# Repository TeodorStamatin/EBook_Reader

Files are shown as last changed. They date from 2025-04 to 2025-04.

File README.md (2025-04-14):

# EBook_Reader

## Block Diagram
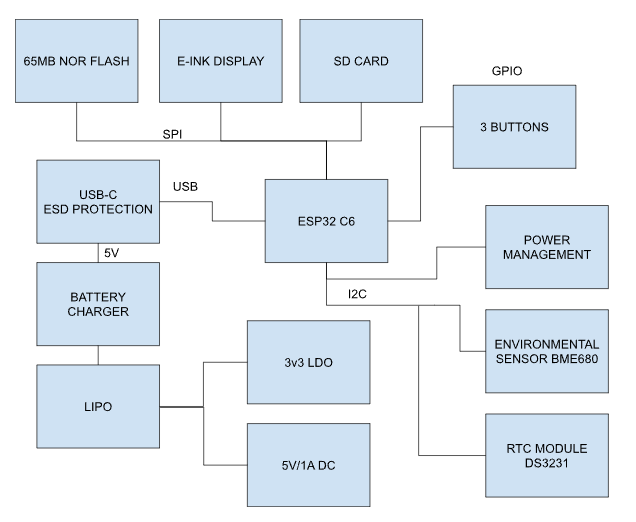
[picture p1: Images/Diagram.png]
Diagram


## BOM (Bill Of Materials)

| Component  | Supplier Link | Datasheet |
|---|---|---|
| 112A-TAAR-R03 | [Model](https://www.snapeda.com/parts/112A-TAAR-R03/Attend/view-part/) | [Datasheet](https://www.snapeda.com/parts/112A-TAAR-R03/Attend/datasheet/) |
| 744043680 | [Model](https://ro.mouser.com/ProductDetail/Wurth-Elektronik/744043680?qs=PGXP4M47uW6VkZq%252BkzjrHA%3D%3D) | [Datasheet](https://www.we-online.com/components/products/datasheet/744043680.pdf) |
| BD5229G-TR | [Model](https://www.digikey.ee/en/models/658502) | [Datasheet](https://www.rohm.com/datasheet?p=BD5229G&dist=Digi-key&media=referral&source=digi-key.com&campaign=Digi-key) |
| Capacitor 0402 | [Model](https://componentsearchengine.com/part-view/CC0402MRX5R5BB106/YAGEO) | [Datasheet](https://componentsearchengine.com/Datasheets/2/CC0402MRX5R5BB106.pdf) |
| CPH3225A | [Model](https://www.snapeda.com/parts/CPH3225A/Seiko+Instruments/view-part/?ref=eda) | [Datasheet](https://www.snapeda.com/parts/CPH3225A/Seiko%20Instruments/datasheet/) |
| Custom Button | [Model](https://industry.panasonic.com/global/en/products/control/switch/light-touch/number/evqpuj02k) | [Datasheet](https://industry.panasonic.com/global/en/downloads?tab=catalog&small_g_cd=203&part_no=EVQPUJ02K) |
| DS3231SN | [Model](https://www.snapeda.com/parts/DS3231SN%23/Analog+Devices/view-part/?ref=eda) | [Datasheet](https://www.snapeda.com/parts/DS3231SN%23/Analog%20Devices/datasheet/) |
| ESP32 WROVER 0805 Capacitor | [Model](https://ro.mouser.com/ProductDetail/KYOCERA-AVX/SD0805S020S1R0?qs=jCA%252BPfw4LHbpkAoSnwrdjw%3D%3D) | [Datasheet](https://ro.mouser.com/datasheet/2/40/schottky-3165252.pdf) |
| ESP32 WROVER BME680 Sensor | [Model](https://www.digikey.ro/en/models/7401317) | [Datasheet](https://www.bosch-sensortec.com/media/boschsensortec/downloads/datasheets/bst-bme680-ds001.pdf) |
| ESP32 WROVER MCP73831 Power Management | [Model](https://www.snapeda.com/parts/MCP73831T-2ACI/OT/Microchip/view-part/) | [Datasheet](https://www.snapeda.com/parts/MCP73831T-2ACI/OT/Microchip/datasheet/) |
| ESP32C6 Varistor 1812 | [Model](https://www.snapeda.com/parts/RC0603JR-070RL/Yageo/view-part/) | [Datasheet](https://www.snapeda.com/parts/RC0603JR-070RL/Yageo/datasheet/) |
| ESP32C6 WROOM-1-N8 | [Model](https://www.snapeda.com/parts/ESP32-C6-WROOM-1-N8/Espressif+Systems/view-part/?ref=eda) | [Datasheet](https://www.snapeda.com/parts/ESP32-C6-WROOM-1-N8/Espressif%20Systems/datasheet/) |
| FH34SRJ-24S-0.5SH | [Model](https://www.snapeda.com/parts/FH34SRJ-24S-0.5SH(99)/Hirose/view-part/) | [Datasheet](https://www.snapeda.com/parts/FH34SRJ-24S-0.5SH(99)/Hirose%20Connector/datasheet/) |
| LED Chip 0603 | [Model](https://grabcad.com/library/0603-smd-led-1) | [Datasheet](https://www.snapeda.com/parts/KP-1608SURCK/Kingbright/datasheet/) |
| MAX17048G+T10 | [Model](https://www.snapeda.com/parts/MAX17048G+T10/Analog+Devices/view-part/?ref=eda) | [Datasheet](https://www.snapeda.com/parts/MAX17048G+T10/Analog%20Devices/datasheet/) |
| MBR0530 Schottky Diode | [Model](https://www.snapeda.com/parts/MBR0530/Onsemi/view-part/?ref=eda) | [Datasheet](https://www.snapeda.com/parts/MBR0530/ON%20Semiconductor/datasheet/) |
| PGB1010603MR | [Model](https://www.snapeda.com/parts/PGB1010603MR/Littelfuse/view-part/?ref=eda) | [Datasheet](https://www.snapeda.com/parts/PGB1010603MR/Littelfuse%20Inc./datasheet/) |
| QWIIC Connector | [Model](https://www.snapeda.com/parts/PRT-14417/SparkFun/view-part/) | [Datasheet](https://www.snapeda.com/parts/PRT-14417/SparkFun%20Electronics/datasheet/) |
| RCL CPOL 3528 | [Model](https://www.snapeda.com/parts/TAJB475K025RNJ/AVX/view-part/?ref=dk&t=capacitor%203528&con_ref=None) | [Datasheet](https://s3.amazonaws.com/snapeda/datasheet/TAJB475K025RNJ_AVX.pdf) |
| Resistor 0402 | [Model](https://componentsearchengine.com/part-view/R0402%201%25%20100%20K%20(RC0402FR-07100KL)/YAGEO) | [Datasheet](https://www.yageo.com/upload/media/product/products/datasheet/rchip/PYu-RC_Group_51_RoHS_L_12.pdf) |
| SI1308EDL-T1-GE3 MOSFET | [Model](https://www.snapeda.com/parts/SI1308EDL-T1-GE3/Vishay+Siliconix/view-part/?ref=eda) | [Datasheet](https://www.snapeda.com/parts/SI1308EDL-T1-GE3/Vishay%20Siliconix/datasheet/) |
| SJ | [Model](https://grabcad.com/library/solder-jumpers-1) | [Datasheet]() |
| TPTP20R | [Model](https://ro.mouser.com/ProductDetail/Adafruit/3825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) | [Datasheet](https://cdn-shop.adafruit.com/product-files/3825/3825_diagram.PDF) |
| USB4110-GF-A | [Model](https://componentsearchengine.com/part-view/USB4110-GF-A/GCT%20(GLOBAL%20CONNECTOR%20TECHNOLOGY)) | [Datasheet](https://gct.co/files/drawings/usb4110.pdf) |
| USBLC6-2SC6Y | [Model](https://www.snapeda.com/parts/USBLC6-2SC6Y/STMicroelectronics/view-part/?ref=eda) | [Datasheet](https://www.snapeda.com/parts/USBLC6-2SC6Y/STMicroelectronics/datasheet/) |
| W25Q512JVEIQ | [Model](https://www.digikey.ro/en/models/10244706) | [Datasheet](https://www.winbond.com/resource-files/W25Q512JV%20SPI%20RevB%2006252019%20KMS.pdf) |
| XC6220A331MR-G | [Model](https://componentsearchengine.com/part-view/XC6220A331MR-G/Torex) | [Datasheet](https://product.torexsemi.com/system/files/series/xc6220.pdf) |

## Hardware Description
1. Microcontroller - ESP32-C6-WROOM-1-N8
The ESP32-C6 is the core processing unit responsible for handling all system operations, communication with sensors and modules, and power management.
- Architecture: RISC-V 32-bit
- Clock Speed: 160 MHz
- Wireless Connectivity: 2.4 GHz Wi-Fi 6, Bluetooth 5.0

2. Power Management & Battery
Battery Type: Li-Po (Lithium Polymer)
- Capacity: 3.7V, 1800mAh
- Charging Circuit: MCP73831T
- Input Voltage: 5V via USB-C
- Protection Features: Overcharge and deep discharge protection
- Voltage Regulator: LDO regulator ensures a stable 3.3V power supply to all components.

3. Display - E-Paper (E-Ink) Screen
- Size: 7.5 inches
- Resolution: 800x480 pixels
- Communication Interface: SPI

4. SD Card Module
- Type: MicroSD (Supports FAT32)
- Interface: SPI

5. External NOR Flash
- Capacity: 64MB
- Interface: SPI

6. Environmental Sensor - BME688
- Functions: Measures temperature, humidity, air pressure, and gas levels.
- Communication Interface: I2C

7. Real-Time Clock (RTC) - DS3231SN
- Functionality: Maintains time and date even when the system is powered off.
- Communication Interface: I2C

8. USB-C Connector & ESD Protection
- Functionality: Provides power input and data transfer capability.
- Protection: Integrated ESD protection and Schottky diode for reverse polarity safety.

9. Buttons & User Input
- Tactile Push Buttons

10. Communication Interfaces
- GPIO: Used for button controls and general I/O operations.
- SPI: Used for SD card, external flash memory, and e-paper display.
- I2C: Used for the BME688 environmental sensor and DS3231SN RTC module.
- UART: Used for debugging and serial communication.
- Wi-Fi & Bluetooth: Provided by ESP32-C6, allowing wireless connectivity.

## Power Consumption Estimation
| Component | Current Draw (mA) | Voltage (V) | Power (mW) |
|---|---|---|---|
| **ESP32-C6 (Wi-Fi active)** | 200 | 3.3 | 660 |
| **E-Paper Display (Updating)** | 40 | 3.3 | 132 |
| **BME688 Sensor (Measuring)**  | 3.1 | 3.3 | 10.23 |
| **RTC Module (Active)** | 0.15 | 3.3 | 0.495 |
| **SD Card (Active)** | 50 | 3.3 | 165 |
| **External NOR Flash** | 25 | 3.3 | 82.5 |
| **Total Estimated Power Consumption** | **~318.5mA** | 3.3V | **1050.72 mW** |

## ESP32-C6 Pin Mapping  

| Component | ESP32-C6 Pin(s) | Interface | Purpose |
|---|---|---|---|
| **E-Paper Display** | IO7 (MOSI), IO6 (SCK), IO10 (CS), IO5 (DC), IO23 (RST), IO3 (BUSY) | SPI | Transfers image data to the display and controls its state. |
| **MicroSD Card** | IO7 (MOSI), IO6 (SCK), IO4 (SS_SD), IO2 (MISO) | SPI | Allows storage and retrieval of e-book files. |
| **Environmental Sensor (BME688)** | IO21 (SDA), IO22 (SCL) | I2C | Reads temperature, humidity, pressure, and air quality data. |
| **RTC Module (DS3231)**  | IO21 (SDA), IO22 (SCL), IO18 (RST), IO1 (32KHz), IO0 (INT_RTC) | I2C | Keeps track of time even when ESP32 is off. |
| **External NOR Flash** | IO11 (CS), IO6 (SCK), IO2 (MISO), IO7 (MOSI) | SPI | Provides additional storage for application data. |
| **Battery Monitoring** | IO21 (SDA), IO22 (SCL) | I2C | Reads battery voltage and charge status. |
| **USB-C Connection** | GPIOs through voltage regulation | USB | Powers and programs the ESP32-C6. |
| **Control Buttons** | IO9 (BOOT), IO15 (CHANGE), EN (RESET) | GPIO | User input for device interactions. |

## Additional Design Notes  

- **Footprint Adjustments**:  
  - The **744043680 inductor** and **USB-C connector** footprints were modified to prevent design rule check (DRC) errors.  

- **Power Routing Constraints**:  
  - Not all power traces could be routed on the **top layer**, requiring some to be placed on the **bottom layer**.  
  - A **ground plane** is present on both the **top** and **bottom layers** for improved signal integrity and noise reduction.  

- **Component Placement**:  
  - The **component layout** closely follows the reference document to ensure optimal spacing and routing efficiency.  
  - The **battery fits perfectly** next to the PCB inside the enclosure.  

- **Button Alignment Issues**:  
  - The buttons **do not align perfectly** with their footprints, but they (hopefully) remain functional.  

- **Via Count and Stitching**:  
  - The design includes **79 vias**, which is a reasonable number for a project of this complexity.  
  - **Via stitching** was applied near the **ESP32-C6** to:  
    - Improve **ground return paths**.  
    - Manage **ground loops**.  
    - Enhance **heat dissipation**.  
    - Reduce **electromagnetic interference (EMI)**.

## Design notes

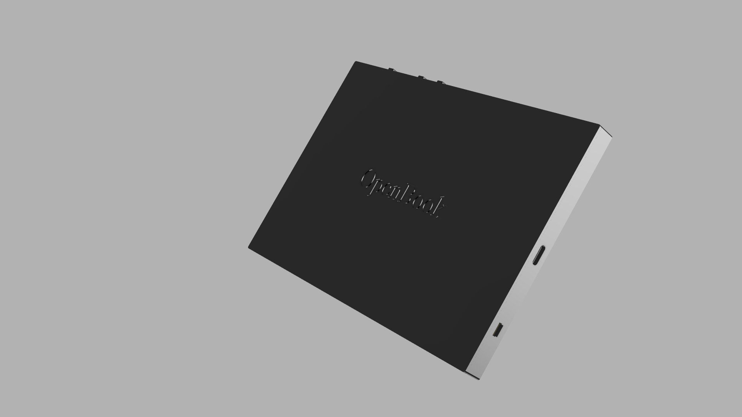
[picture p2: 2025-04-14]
Images/OpenBookReader2.png

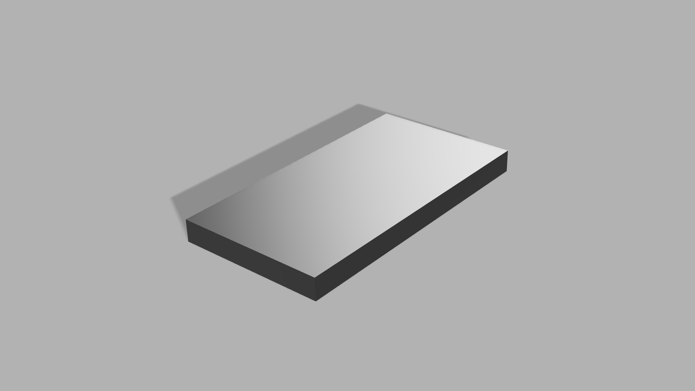
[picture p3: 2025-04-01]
Images/Battery.png

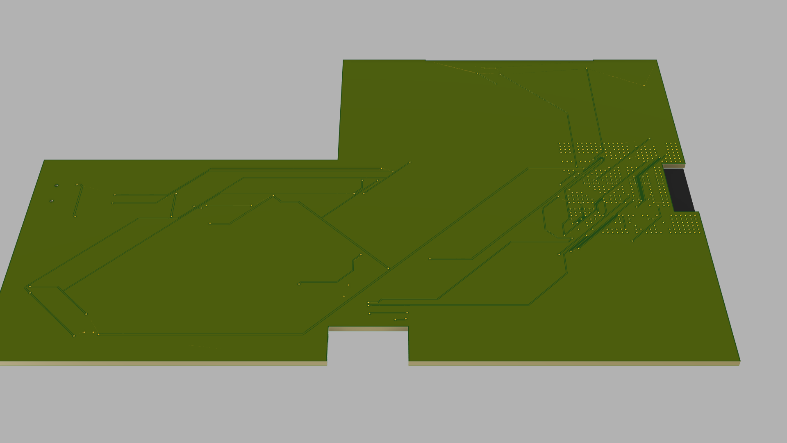
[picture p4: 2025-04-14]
Images/PCB_bottom.png

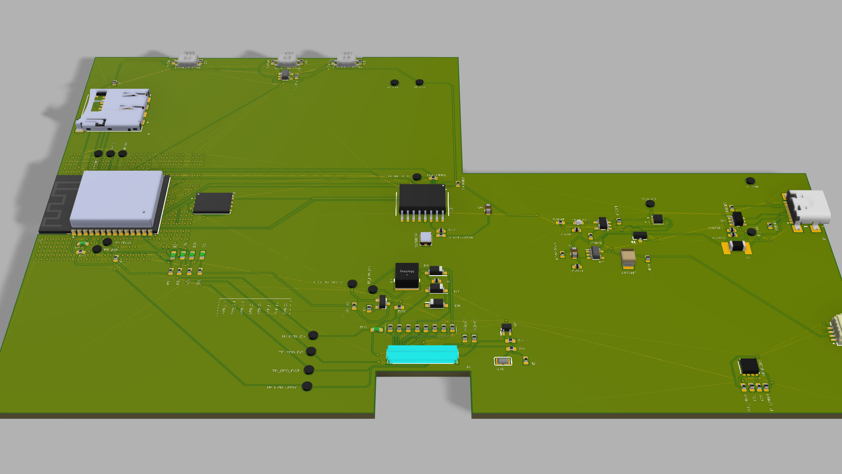
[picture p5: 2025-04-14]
Images/PCB_TOP.png

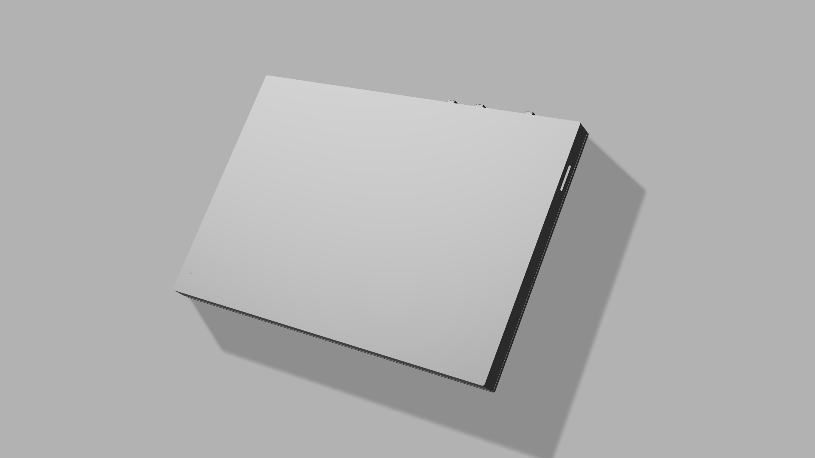
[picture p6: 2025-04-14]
Images/OpenBookReader1.png

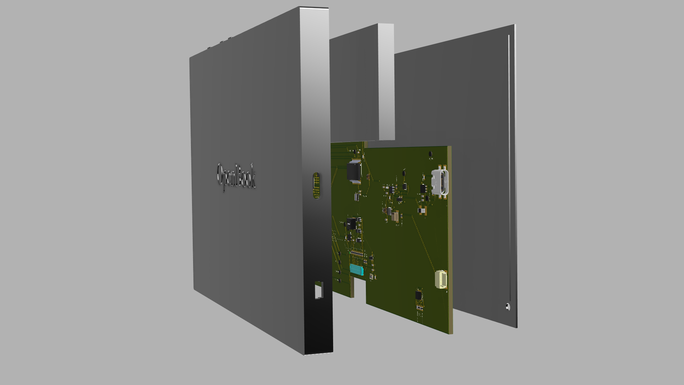
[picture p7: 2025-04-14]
Images/OpenBookReader_exploded1.png

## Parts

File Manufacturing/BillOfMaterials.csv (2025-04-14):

Qty,Value,Device,Package,Parts,Description,ARROW_PART_NUMBER,ARROW_PRICE-STOCK,AVAILABILITY,CENTROID_NOT_SPECIFIED,CHECK_PRICES,COPYRIGHT,DATASHEET,DESCRIPTION.1,DIGIKEY_DESCRIPTION,DIGIKEY_PART_NUMBER,HEIGHT,LEAD_FREE,MANUFACTURER_NAME,MANUFACTURER_PART_NUMBER,MF,MFR_NAME,MOUSER_PART_NUMBER,MOUSER_PRICE-STOCK,MOUSER_TESTING_PART_NUMBER,MOUSER_TESTING_PRICE-STOCK,MP,MPN,PACKAGE.1,POPULARITY,PREFIX,PRICE,PROD_ID,PURCHASE-URL,ROHS,SNAPEDA_LINK,SPICEMODEL,SPICEPREFIX,TEMPERATURE_RANGE_HIGH,TEMPERATURE_RANGE_LOW,TP_SIGNAL_NAME,VALUE.1,LCSC Part Number
1,,ADAFRUIT_LEDCHIP-LED0603,ADAFRUIT_CHIP-LED0603,CHG_LED,LED,,,,,,,,,,,,,,,,,,,,,,,,,,,,,,,,,,,,
1,,SJ,SJ,SJ1,SMD solder JUMPER,,,,,,,,,,,,,,,,,,,,,,,,3,,,,,,,,,,,,
1,0.1uF/50V,EAGLE-LTSPICE_CC0402,ESP32_WROVER_EAGLE-LTSPICE_C0402,EPD_C3,CAPACITOR, European symbol,,,,,,,,,,,,,,,,,,,,,,,,,,,,,,,NONE,C,,,,,
1,0.47,ESP32_WROVER_EAGLE-LTSPICE_RR0402,ESP32_WROVER_EAGLE-LTSPICE_R0402,R7,RESISTOR, European symbol,,,,,,,,,,,,,,,,,,,,,,,,,,,,,,,NONE,R,,,,,
1,100K,ESP32_WROVER_EAGLE-LTSPICE_RR0402,ESP32_WROVER_EAGLE-LTSPICE_R0402,R4PWRUSB1,RESISTOR, European symbol,,,,,,,,,,,,,,,,,,,,,,,,,,,,,,,NONE,R,,,,,
9,100nF,EAGLE-LTSPICE_CC0402,ESP32_WROVER_EAGLE-LTSPICE_C0402,C1USB, C2USB1, C6, C21, C22, C24, C25, C26, C_DELAY,CAPACITOR, European symbol,,,,,,,,,,,,,,,,,,,,,,,,,,,,,,,NONE,C,,,,,
1,100uF,RCL_CPOL-EUCT3528,RCL_CT3528,C5TANT,POLARIZED CAPACITOR, European symbol,,,,,,,,,,,,,,,,,,,,,,,,0,,,,,,,,C,,,,,
16,10K,ESP32_WROVER_EAGLE-LTSPICE_RR0402,ESP32_WROVER_EAGLE-LTSPICE_R0402,R6, R10, R11_CL1, R12_PINH, R13_PINH, R14_PINH1, R15_PINH1, R16, R17, R18, R19, R20, R21, R_BOOT, R_CHANGE, R_RESET,RESISTOR, European symbol,,,,,,,,,,,,,,,,,,,,,,,,,,,,,,,NONE,R,,,,,
1,10uF,EAGLE-LTSPICE_CC0402,ESP32_WROVER_EAGLE-LTSPICE_C0402,C7,CAPACITOR, European symbol,,,,,,,,,,,,,,,,,,,,,,,,,,,,,,,NONE,C,,,,,
1,112A-TAAR-R03_ATTEND,112A-TAAR-R03_ATTEND,112ATAARR03ATTEND,J2,Micro SD Card Socket, Push-Push Type, Top Mount, SMT, H=1.83mm, 10u,,,,,,,,Micro SD Card Socket, Push-Push Type, Top Mount, SMT, H=1.83mm, 10u,,,1.9mm,,ATTEND,112A-TAAR-R03 ATTEND,,,,,,,,,,,,,,,,,,
1,15,ESP32_WROVER_EAGLE-LTSPICE_RR0402,ESP32_WROVER_EAGLE-LTSPICE_R0402,R_CAPACITOR,RESISTOR, European symbol,,,,,,,,,,,,,,,,,,,,,,,,,,,,,,,NONE,R,,,,,
1,1uF,EAGLE-LTSPICE_CC0402,ESP32_WROVER_EAGLE-LTSPICE_C0402,C23,CAPACITOR, European symbol,,,,,,,,,,,,,,,,,,,,,,,,,,,,,,,NONE,C,,,,,
9,1uF/50V,EAGLE-LTSPICE_CC0402,ESP32_WROVER_EAGLE-LTSPICE_C0402,EPD_C1, EPD_C2, EPD_C6, EPD_C7, EPD_C8, EPD_C9, EPD_C10, EPD_C11, EPD_C12,CAPACITOR, European symbol,,,,,,,,,,,,,,,,,,,,,,,,,,,,,,,NONE,C,,,,,
1,02.feb,ESP32_WROVER_EAGLE-LTSPICE_RR0402,ESP32_WROVER_EAGLE-LTSPICE_R0402,R5,RESISTOR, European symbol,,,,,,,,,,,,,,,,,,,,,,,,,,,,,,,NONE,R,,,,,
1,200,ESP32_WROVER_EAGLE-LTSPICE_RR0402,ESP32_WROVER_EAGLE-LTSPICE_R0402,R8BAT,RESISTOR, European symbol,,,,,,,,,,,,,,,,,,,,,,,,,,,,,,,NONE,R,,,,,
2,20V/4.2A/52mO/1.4W,ESP32_WROVER_SPARKFUN-DISCRETESEMI_MOSFET_PCH-DMG2305UX-7,ESP32_WROVER_SPARKFUN-DISCRETESEMI_SOT23-3,Q1, Q3,P-channel MOSFETs,,,,,,,,,,,,,,,,,,,,,,,,,,,TRAN-14388,,,,,,,,,20V/4.2A/52mO/1.4W,
1,2K,ESP32_WROVER_EAGLE-LTSPICE_RR0402,ESP32_WROVER_EAGLE-LTSPICE_R0402,R9BAT,RESISTOR, European symbol,,,,,,,,,,,,,,,,,,,,,,,,,,,,,,,NONE,R,,,,,
4,4.7uF,EAGLE-LTSPICE_CC0402,ESP32_WROVER_EAGLE-LTSPICE_C0402,C3BAT, C4BAT, C9BAT, C10BAT,CAPACITOR, European symbol,,,,,,,,,,,,,,,,,,,,,,,,,,,,,,,NONE,C,,,,,
1,4.7uF/25V,EAGLE-LTSPICE_CC0402,ESP32_WROVER_EAGLE-LTSPICE_C0402,C8,CAPACITOR, European symbol,,,,,,,,,,,,,,,,,,,,,,,,,,,,,,,NONE,C,,,,,
2,5K1,ESP32_WROVER_EAGLE-LTSPICE_RR0402,ESP32_WROVER_EAGLE-LTSPICE_R0402,R2USB, R3USB1,RESISTOR, European symbol,,,,,,,,,,,,,,,,,,,,,,,,,,,,,,,NONE,R,,,,,
1,68uH,744043680IND_4828-WE-TPC_WRE,IND_4828-WE-TPC_WRE,L2,,,,,,,Copyright (C) 2024 Ultra Librarian. All rights reserved.,,,,,,,,744043680,,Wurth Electronics,,,,,,,,,,,,,,,,,,,,,
1,BD5229G-TR,BD5229G-TR,SOT95P280X125-5N,IC2,Voltage Detector with Adjustable Delay Time: CMOS processes are utilized to develop high precision, low current consumption CMOS reset ICs that allow arbitrary setting of the delay time. The extensive lineup includes both Nch Open Drain and CMOS output types in a wide range of detection voltages (from 2.3V to 6.0V, in 0.1V steps), enabling selection of the ideal solution based on customer requirements. In addition, the entire series is of course both lead-free and RoHS-compliant.,,,,,,,,Voltage Detector with Adjustable Delay Time: CMOS processes are utilized to develop high precision, low current consumption CMOS reset ICs that allow arbitrary setting of the delay time. The extensive lineup includes both Nch Open Drain and CMOS output types in a wide range of detection voltages (from 2.3V to 6.0V, in 0.1V steps), enabling selection of the ideal solution based on customer requirements. In addition, the entire series is of course both lead-free and RoHS-compliant.,,,1.25mm,,ROHM Semiconductor,BD5229G-TR,,,755-BD5229G-TR,https://www.mouser.co.uk/ProductDetail/ROHM-Semiconductor/BD5229G-TR?qs=4kLU8WoGk0vvnhrrYwdszw%3D%3D,,,,,,,,,,,,,,,
3,BUTTON_CUSYOMV1,BUTTON_CUSYOMV1,MYBUTTON,BOOT_BUTTON, CHANGE_BUTTON, RESET_BUTTON,,,,,,,,,,,,,,,,,,,,,,,,,,,,,,,,,,,,,,
1,CPH3225A,CPH3225A,CAPCP3225X100N,SUPERCAP,Cap 0.011F 3.3V 1210 Flat Check availability,,,Not in stock,,https://www.snapeda.com/parts/CPH3225A/Seiko+Instruments/view-part/?ref=eda,,, 11 mF (EDLC) Supercapacitor 3.3 V 1210 (3225 Metric) - - ,,,,,,,Seiko Instruments,,,,,,CPH3225A,,1210 Seiko,,,None,,https://www.snapeda.com/api/url_track_click_mouser/?unipart_id=562593&manufacturer=Seiko Instruments&part_name=CPH3225A&search_term=None,,https://www.snapeda.com/parts/CPH3225A/Seiko+Instruments/view-part/?ref=snap,,,,,,,
1,DS3231SN#,DS3231SN#,SOIC127P1032X265-16N,U5,Real Time Clock Serial 16-Pin SOIC W T/R     Check availability,,,In Stock,,https://www.snapeda.com/parts/DS3231SN%23/Analog+Devices/view-part/?ref=eda,,, Extremely Accurate I?C-Integrated RTC/TCXO/Crystal ,,,,,,,Analog Devices,,,,,,DS3231SN#,,SOIC-16 Maxim,,,None,,https://www.snapeda.com/api/url_track_click_mouser/?unipart_id=99048&manufacturer=Analog Devices&part_name=DS3231SN#&search_term=None,,https://www.snapeda.com/parts/DS3231SN%23/Analog+Devices/view-part/?ref=snap,,,,,,,
1,ESP32-C6-WROOM-1-N8,ESP32-C6-WROOM-1-N8,XCVR_ESP32-C6-WROOM-1-N8,U2,Check availability,,,In Stock,,https://www.snapeda.com/parts/ESP32-C6-WROOM-1-N8/Espressif+Systems/view-part/?ref=eda,,, Multiprotocol Modules ESP32-C6 module, Wi-Fi 6 in 2.4 GHz band, Bluetooth 5, Zigbee 3.0 and Thread. ESP34-WROOM Compatible - ENGINEERING SAMPLE ,,,,,,,Espressif Systems,,,,,,ESP32-C6-WROOM-1-N8,,None,,,None,,,,https://www.snapeda.com/parts/ESP32-C6-WROOM-1-N8/Espressif+Systems/view-part/?ref=snap,,,,
1,ESP32C6_VARISTORCN1812,ESP32C6_VARISTORCN1812,ESP32C6_VARISTOR_CT/CN1812,R1,VARISTOR,,,,,,,,,,,,,,,,,,,,,,,,0,,,,,,,,,,,,,
2,ESP32_WROVER_AVX---SD0805S020S1R0_AVX_SD0805S020S1R0_0_0AVX_SD0805S020S1R0_0_0,ESP32_WROVER_AVX---SD0805S020S1R0_AVX_SD0805S020S1R0_0_0AVX_SD0805S020S1R0_0_0,ESP32_WROVER_AVX---SD0805S020S1R0_AVX_SD0805S020S1R0_0,D2, D6,Schottky Barrier Rectifier Diode,,,,No,,,http://datasheets.avx.com/schottky.pdf,,DIODE SCHOTTKY 20V 1A 0805,478-7800-1-ND,,yes,,,AVX,,581-SD0805S020S1R0,,,,,,0805 (2012 metric),,D,,,,yes,,,,+125°C,-55°C,,,
1,ESP32_WROVER_BME680_BME680,ESP32_WROVER_BME680_BME680,ESP32_WROVER_BME680_PSON80P300X300X100-8N,SENSOR2,Integrated Environmental Unit,,,Unavailable,,,,, Integrated Environmental Unit ,,,,,,,Bosch Sensortec,,,,,,BME680,,LGA-8 Bosch Tools,,,None,,,,,,,,,,,
1,ESP32_WROVER_SPARKFUN-IC-POWER_MCP73831,ESP32_WROVER_SPARKFUN-IC-POWER_MCP73831,ESP32_WROVER_SPARKFUN-IC-POWER_SOT23-5,U1,MCP73831T Li-Ion, Li-Pol Controller,,,,,,,,,,,,,,,,,,,,,,,,,,,IC-09995,,,,,,,,,,
1,FH34SRJ-24S-0.5SH_99_,FH34SRJ-24S-0.5SH_99_,FH34SRJ24S05SH99,J3, (0.50mm) Surface Mount, Right Angle,,,,,,,,24 Position FFC, FPC Connector Contacts, (0.50mm) Surface Mount, Right Angle,,,1.1mm,,Hirose,FH34SRJ-24S-0.5SH(99),,,798-FH34SRJ24S05SH99,https://www.mouser.co.uk/ProductDetail/Hirose-Connector/FH34SRJ-24S-0.5SH99
1,MAX17048G+T10,MAX17048G+T10,SON50P200X200X80-9N,U4,Check availability,,,In Stock,,https://www.snapeda.com/parts/MAX17048G+T10/Analog+Devices/view-part/?ref=eda,,, 3µA 1-Cell/2-Cell Fuel Gauge with ModelGauge ,,,,,,,Analog Devices,,,,,,MAX17048G+T10,,TDFN-8 Maxim,,,None,,https://www.snapeda.com/api/url_track_click_mouser/?unipart_id=329239&manufacturer=Analog Devices&part_name=MAX17048G+T10&search_term=None,,https://www.snapeda.com/parts/MAX17048G+T10/Analog+Devices/view-part/?ref=snap,,,,,,,
3,MBR0530,MBR0530,SOD3716X135N,D3, D4, D5,ON SEMICONDUCTOR - MBR0530 - DIODE, SCHOTTKY, 0.5A, 30V, SOD-123,,,In Stock,,https://www.snapeda.com/parts/MBR0530/Onsemi/view-part/?ref=eda,,, Diode Schottky 30 V 500mA Surface Mount SOD-123 ,,,,,,,ON Semiconductor,,,,,,MBR0530,,SOD-123-2 ON Semiconductor,,,None,,https://www.snapeda.com/api/url_track_click_mouser/?unipart_id=179458&manufacturer=ON Semiconductor&part_name=MBR0530&search_term=None,,https://www.snapeda.com/parts/MBR0530/Onsemi/view-part/?ref=snap,,,,,,,
6,PGB1010603MR,PGB1010603MR,DIOC1608X36N,D7, D8, D9, D10, D11, D12,Check availability,,,In Stock,,https://www.snapeda.com/parts/PGB1010603MR/Littelfuse/view-part/?ref=eda,,, 150V (Typ) Clamp - Ipp Tvs Diode Surface Mount 0603 (1608 Metric) ,,,,,,,Littelfuse Inc.,,,,,,PGB1010603MR,,0603 Littelfuse Inc.,,,None,,https://www.snapeda.com/api/url_track_click_mouser/?unipart_id=5659453&manufacturer=Littelfuse Inc.&part_name=PGB1010603MR&search_term=None,,https://www.snapeda.com/parts/PGB1010603MR/Littelfuse/view-part/?ref=snap,,,,,,,
1,QWIIC_RIGHT_ANGLE,QWIIC_CONNECTORJS-1MM,JST04_1MM_RA,J4,SparkFun I2C Standard Qwiic Connector,,,,,,,,,,,,,,,,,,,,,,,,,,,CONN-13694,,,,,,,,,QWIIC_RIGHT_ANGLE,
1,SAMACSYS_PARTS_USB4110-GF-A,SAMACSYS_PARTS_USB4110-GF-A,SAMACSYS_PARTS_USB4110GFA,J1,CONN USB 2.0 TYPE-C R/A SMT,,,,,,,,CONN USB 2.0 TYPE-C R/A SMT,,,3.26mm,,GCT (GLOBAL CONNECTOR TECHNOLOGY),USB4110-GF-A,,,640-USB4110-GF-A,https://www.mouser.co.uk/ProductDetail/GCT/USB4110-GF-A
1,SI1308EDL-T1-GE3,SI1308EDL-T1-GE3,SOT65P210X110-3N,Q2,MOSFET N-Ch 30V 1.5A TrenchFET SC70 Vishay Si1308EDL-T1-GE3 N-channel MOSFET Transistor, 1.5 A, 30 V, 3-Pin SC-70,,,In Stock,,https://www.snapeda.com/parts/SI1308EDL-T1-GE3/Vishay+Siliconix/view-part/?ref=eda,,, Si1308EDL-T1-GE3 N-channel MOSFET Transistor, 1.5 A, 30 V, 3-Pin SC-70 | Siliconix / Vishay SI1308EDL-T1-GE3 ,,,,,,,Vishay Siliconix,,,,,,SI1308EDL-T1-GE3,,SOT-323 Vishay Semiconductor,,,None,,https://www.snapeda.com/api/url_track_click_mouser/?unipart_id=274603&manufacturer=Vishay Siliconix&part_name=SI1308EDL-T1-GE3&search_term=None,,https://www.snapeda.com/parts/SI1308EDL-T1-GE3/Vishay+Siliconix/view-part/?ref=snap,,,,
17,TPTP20R,TPTP20R,TP20R,TP_3V3, TP_EPD_3V3, TP_EPD_3V3_C, TP_EPD_BUSY, TP_EPD_CS, TP_EPD_DC, TP_EPD_RST, TP_GND, TP_GND1, TP_INT_RTC, TP_MISO, TP_MOSI, TP_RX, TP_SCK, TP_TX, TP_VBAT, TP_VBUS,Test pad,,,,,,,,,,,,,,,,,,,,,,,,2,,,,,,,,,,,,,
1,USBLC6-2SC6Y,USBLC6-2SC6Y,SOT95P280X145-6N,D1,Low Cap. ESD Protection Auto SOT-23-6 STMicroelectronics USBLC6-2SC6Y, Dual Uni-Directional TVS Diode Array, 6-Pin SOT-23,,,In Stock,,https://www.snapeda.com/parts/USBLC6-2SC6Y/STMicroelectronics/view-part/?ref=eda,,, 17V Clamp 5A (8/20µs) Ipp Tvs Diode Surface Mount SOT-23-6 ,,,,,,,STMicroelectronics,,,,,,USBLC6-2SC6Y,,SOT-23-6 STMicroelectronics,,,None,,,,https://www.snapeda.com/parts/USBLC6-2SC6Y/STMicroelectronics/view-part/?ref=snap,,,,,,,
1,W25Q512JVEIQ,W25Q512JVEIQ,SON127P600X800X80-9N,U6,Check availability,,,In Stock,,https://www.snapeda.com/parts/W25Q512JVEIQ/Winbond+Electronics/view-part/?ref=eda,,, FLASH - NOR Memory IC 512Mb (64M x 8) SPI - Quad I/O 133 MHz 8-WSON (8x6) ,,,,,,,Winbond Electronics,,,,,,W25Q512JVEIQ,,Package ,,,None,,,,https://www.snapeda.com/parts/W25Q512JVEIQ/Winbond+Electronics/view-part/?ref=snap,,,,,,,
1,XC6220A331MR-G,XC6220A331MR-G,SOT95P280X120-5N,IC1,LDO Voltage Regulators,,,,,,,,LDO Voltage Regulators,,,1.2mm,,Torex,XC6220A331MR-G,,,865-XC6220A331MR-G,https://www.mouser.co.uk/ProductDetail/Torex-Semiconductor/XC6220A331MR-G

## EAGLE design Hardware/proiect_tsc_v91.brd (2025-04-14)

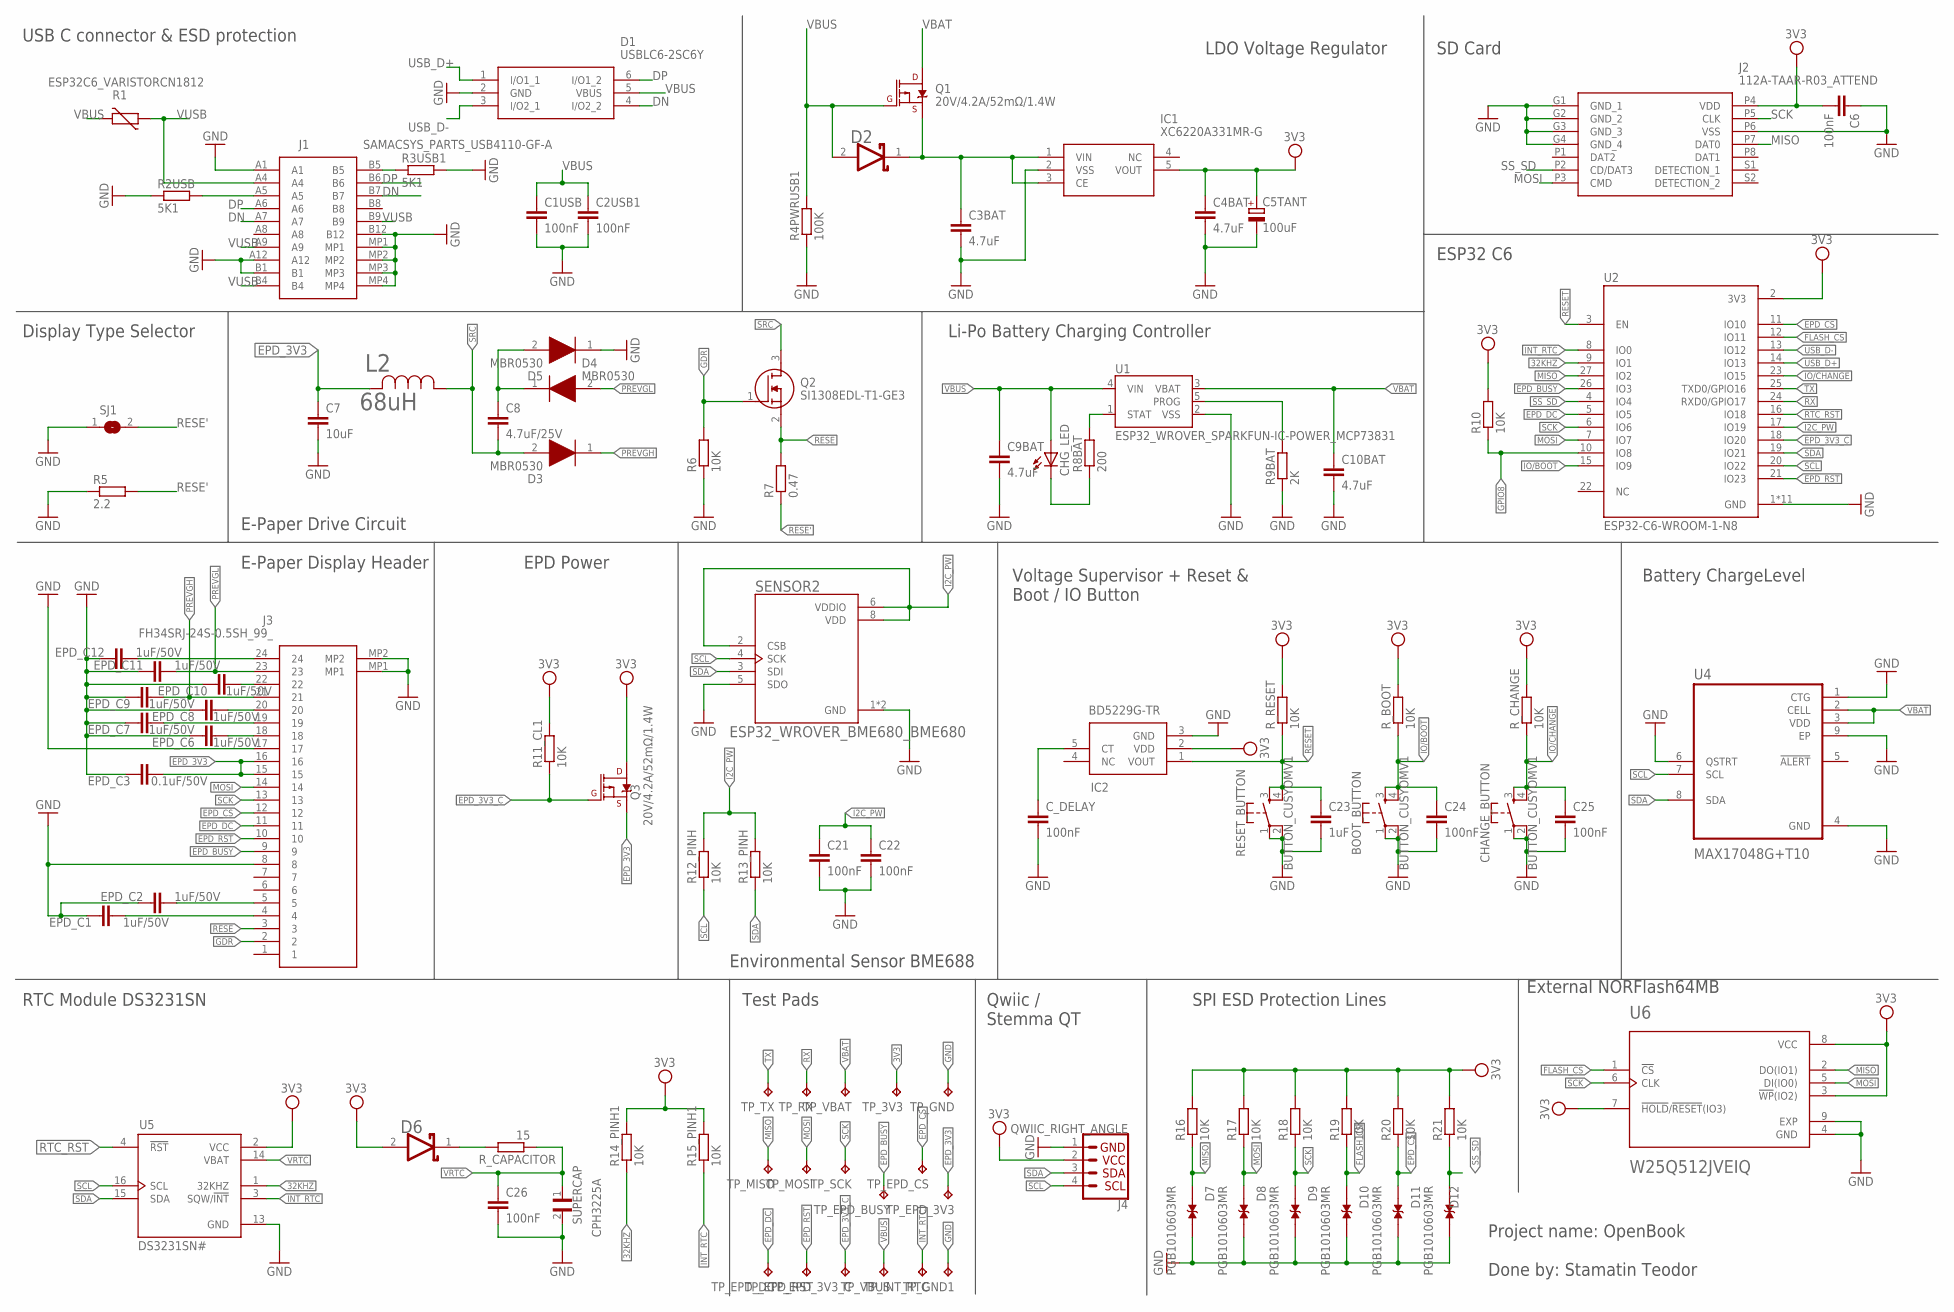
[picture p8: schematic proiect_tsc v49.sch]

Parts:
BOOT_BUTTON: BUTTON_CUSYOMV1; MYBUTTON
C1USB, C2USB1, C6, C21, C22, C24, C25, C26: 100nF; ESP32_WROVER_EAGLE-LTSPICE_C0402
C3BAT, C4BAT, C9BAT, C10BAT: 4.7uF; ESP32_WROVER_EAGLE-LTSPICE_C0402
C5TANT: 100uF; RCL_CT3528
C7: 10uF; ESP32_WROVER_EAGLE-LTSPICE_C0402
C8: 4.7uF/25V; ESP32_WROVER_EAGLE-LTSPICE_C0402
C23: 1uF; ESP32_WROVER_EAGLE-LTSPICE_C0402
CHANGE_BUTTON: BUTTON_CUSYOMV1; MYBUTTON
CHG_LED: ADAFRUIT_LEDCHIP-LED0603; ADAFRUIT_CHIP-LED0603
C_DELAY: 100nF; ESP32_WROVER_EAGLE-LTSPICE_C0402
D1: USBLC6-2SC6Y; SOT95P280X145-6N
D2, D6: ESP32_WROVER_AVX---SD0805S020S1R0_AVX_SD0805S020S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; ESP32_WROVER_AVX---SD0805S020S1R0_AVX_SD0805S020S1R0_0
D3, D4, D5: MBR0530; SOD3716X135N
D7, D8, D9, D10, D11, D12: PGB1010603MR; DIOC1608X36N
EPD_C1, EPD_C2, EPD_C6, EPD_C7, EPD_C8, EPD_C9, EPD_C10, EPD_C11, EPD_C12: 1uF/50V; ESP32_WROVER_EAGLE-LTSPICE_C0402
EPD_C3: 0.1uF/50V; ESP32_WROVER_EAGLE-LTSPICE_C0402
IC1: XC6220A331MR-G; SOT95P280X120-5N
IC2: BD5229G-TR; SOT95P280X125-5N
J1: SAMACSYS_PARTS_USB4110-GF-A; SAMACSYS_PARTS_USB4110GFA
J2: 112A-TAAR-R03_ATTEND; 112ATAARR03ATTEND
J3: FH34SRJ-24S-0.5SH_99_; FH34SRJ24S05SH99
J4: QWIIC_RIGHT_ANGLE; JST04_1MM_RA
L2: 68uH; IND_4828-WE-TPC_WRE
Q1, Q3: 20V/4.2A/52mΩ/1.4W; ESP32_WROVER_SPARKFUN-DISCRETESEMI_SOT23-3
Q2: SI1308EDL-T1-GE3; SOT65P210X110-3N
R1: ESP32C6_VARISTORCN1812; ESP32C6_VARISTOR_CT/CN1812
R2USB, R3USB1: 5K1; ESP32_WROVER_EAGLE-LTSPICE_R0402
R4PWRUSB1: 100K; ESP32_WROVER_EAGLE-LTSPICE_R0402
R5: 2.2; ESP32_WROVER_EAGLE-LTSPICE_R0402
R6, R10, R11_CL1, R12_PINH, R13_PINH, R14_PINH1, R15_PINH1, R16, R17, R18, R19, R20, R21: 10K; ESP32_WROVER_EAGLE-LTSPICE_R0402
R7: 0.47; ESP32_WROVER_EAGLE-LTSPICE_R0402
R8BAT: 200; ESP32_WROVER_EAGLE-LTSPICE_R0402
R9BAT: 2K; ESP32_WROVER_EAGLE-LTSPICE_R0402
RESET_BUTTON: BUTTON_CUSYOMV1; MYBUTTON
R_BOOT: 10K; ESP32_WROVER_EAGLE-LTSPICE_R0402
R_CAPACITOR: 15; ESP32_WROVER_EAGLE-LTSPICE_R0402
R_CHANGE: 10K; ESP32_WROVER_EAGLE-LTSPICE_R0402
R_RESET: 10K; ESP32_WROVER_EAGLE-LTSPICE_R0402
SENSOR2: ESP32_WROVER_BME680_BME680; ESP32_WROVER_BME680_PSON80P300X300X100-8N
SJ1: SJ
SUPERCAP: CPH3225A; CAPCP3225X100N
TP_3V3: TPTP20R; TP20R
TP_EPD_3V3, TP_EPD_3V3_C: TPTP20R; TP20R
TP_EPD_BUSY: TPTP20R; TP20R
TP_EPD_CS: TPTP20R; TP20R
TP_EPD_DC: TPTP20R; TP20R
TP_EPD_RST: TPTP20R; TP20R
TP_GND, TP_GND1: TPTP20R; TP20R
TP_INT_RTC: TPTP20R; TP20R
TP_MISO: TPTP20R; TP20R
TP_MOSI: TPTP20R; TP20R
TP_RX: TPTP20R; TP20R
TP_SCK: TPTP20R; TP20R
TP_TX: TPTP20R; TP20R
TP_VBAT: TPTP20R; TP20R
TP_VBUS: TPTP20R; TP20R
U1: ESP32_WROVER_SPARKFUN-IC-POWER_MCP73831; ESP32_WROVER_SPARKFUN-IC-POWER_SOT23-5
U2: ESP32-C6-WROOM-1-N8; XCVR_ESP32-C6-WROOM-1-N8
U4: MAX17048G+T10; SON50P200X200X80-9N
U5: DS3231SN#; SOIC127P1032X265-16N
U6: W25Q512JVEIQ; SON127P600X800X80-9N

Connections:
3V3: C4BAT.1, C5TANT.+, C6.2, D6.2 (ANODE), IC1.5 (VOUT), IC2.2 (VDD), J2.P4 (VDD), J4.2, Q3.3 (D), R10.2, R11_CL1.2, R14_PINH1.2, R15_PINH1.2, R16.2, R17.2, R18.2, R19.2, R20.2, R21.2, R_BOOT.2, R_CHANGE.2, R_RESET.2, TP_3V3.TP, U2.2 (3V3), U5.2 (VCC), U6.3 (!WP!(IO2)), U6.7 (!HOLD!/!RESET!(IO3)), U6.8 (VCC)
32KHZ: R14_PINH1.1, U2.9 (IO1), U5.1 (32KHZ)
DN: D1.4 (I/O2_2), J1.A7, J1.B7
DP: D1.6 (I/O1_2), J1.A6, J1.B6
EPD_3V3: C7.1, EPD_C3.2, J3.15, J3.16, L2.2, Q3.2 (S), TP_EPD_3V3.TP
EPD_3V3_C: Q3.1 (G), R11_CL1.1, TP_EPD_3V3_C.TP, U2.18 (IO20)
EPD_BUSY: J3.9, TP_EPD_BUSY.TP, U2.26 (IO3)
EPD_CS: D11.1, J3.12, R20.1, TP_EPD_CS.TP, U2.11 (IO10)
EPD_DC: J3.11, TP_EPD_DC.TP, U2.5 (IO5)
EPD_RST: J3.10, TP_EPD_RST.TP, U2.21 (IO23)
FLASH_CS: D10.1, R19.1, U2.12 (IO11), U6.1 (!CS)
GDR: J3.2, Q2.1 (G), R6.2
GND: BOOT_BUTTON.1, BOOT_BUTTON.2, C1USB.2, C2USB1.2, C3BAT.2, C4BAT.2, C5TANT.-, C6.1, C7.2, C9BAT.2, C10BAT.2, C21.2, C22.2, C23.2, C24.2, C25.2, C26.2, CHANGE_BUTTON.1, CHANGE_BUTTON.2, C_DELAY.2, D1.2 (GND), D5.1 (K), D7.2, D8.2, D9.2, D10.2, D11.2, D12.2, EPD_C1.1, EPD_C2.1, EPD_C3.1, EPD_C6.1, EPD_C7.1, EPD_C8.1, EPD_C9.1, EPD_C10.1, EPD_C11.1, EPD_C12.1, IC1.2 (VSS), IC2.3 (GND), J1.A1, J1.A12, J1.B1, J1.B12, J1.MP1, J1.MP2, J1.MP3, J1.MP4, J2.G1 (GND_1), J2.G2 (GND_2), J2.G3 (GND_3), J2.G4 (GND_4), J2.P6 (VSS), J3.8, J3.17, J3.MP1, J3.MP2, J4.1, R2USB.1, R3USB1.2, R4PWRUSB1.1, R5.1, R6.1, R9BAT.1, RESET_BUTTON.1, RESET_BUTTON.2, SENSOR2.1 (GND), SENSOR2.5 (SDO), SENSOR2.7 (GND), SJ1.1, SUPERCAP.2, TP_GND.TP, TP_GND1.TP, U1.2 (VSS), U2.1 (GND), U2.28 (GND), U2.29_1 (GND), U2.29_2 (GND), U2.29_3 (GND), U2.29_4 (GND), U2.29_5 (GND), U2.29_6 (GND), U2.29_7 (GND), U2.29_8 (GND), U2.29_9 (GND), U4.1 (CTG), U4.4 (GND), U4.6 (QSTRT), U4.9 (EP), U5.13 (GND), U6.4 (GND), U6.9 (EXP)
GPIO8: R10.1, U2.10 (IO8)
I2C_PW: C21.1, C22.1, R12_PINH.2, R13_PINH.2, SENSOR2.2 (CSB), SENSOR2.6 (VDDIO), SENSOR2.8 (VDD), U2.17 (IO19)
INT_RTC: R15_PINH1.1, TP_INT_RTC.TP, U2.8 (IO0), U5.3 (SQW/!INT)
IO/BOOT: BOOT_BUTTON.3, BOOT_BUTTON.4, C24.1, R_BOOT.1, U2.15 (IO9)
IO/CHANGE: C25.1, CHANGE_BUTTON.3, CHANGE_BUTTON.4, R_CHANGE.1, U2.23 (IO15)
MISO: D7.1, J2.P7 (DAT0), R16.1, TP_MISO.TP, U2.27 (IO2), U6.2 (DO(IO1))
MOSI: D8.1, J2.P3 (CMD), J3.14, R17.1, TP_MOSI.TP, U2.7 (IO7), U6.5 (DI(IO0))
unnamed: J1.A5, R2USB.2
unnamed: EPD_C6.2, J3.18
unnamed: EPD_C1.2, J3.4
unnamed: C3BAT.1, D2.1 (CATHODE), IC1.1 (VIN), IC1.3 (CE), Q1.2 (S)
unnamed: C8.1, D4.1 (K), D5.2 (A)
unnamed: R8BAT.2, U1.1 (STAT)
unnamed: CHG_LED.C, R8BAT.1
unnamed: R9BAT.2, U1.5 (PROG)
unnamed: EPD_C2.2, J3.5
unnamed: J1.B5, R3USB1.1
unnamed: EPD_C7.2, J3.19
unnamed: EPD_C8.2, J3.20
unnamed: C_DELAY.1, IC2.5 (CT)
unnamed: EPD_C10.2, J3.22
unnamed: D6.1 (CATHODE), R_CAPACITOR.2
unnamed: EPD_C12.2, J3.24
PREVGH: D3.1 (K), EPD_C9.2, J3.21
PREVGL: D4.2 (A), EPD_C11.2, J3.23
RESE: J3.3, Q2.2 (S), R7.2
RESE': R5.2, R7.1, SJ1.2
RESET: C23.1, IC2.1 (VOUT), RESET_BUTTON.3, RESET_BUTTON.4, R_RESET.1, U2.3 (EN)
RTC_RST: U2.16 (IO18), U5.4 (!RST)
RX: TP_RX.TP, U2.24 (RXD0/GPIO17)
SCK: D9.1, J2.P5 (CLK), J3.13, R18.1, TP_SCK.TP, U2.6 (IO6), U6.6 (CLK)
SCL: J4.4, R12_PINH.1, SENSOR2.4 (SCK), U2.20 (IO22), U4.7 (SCL), U5.16 (SCL)
SDA: J4.3, R13_PINH.1, SENSOR2.3 (SDI), U2.19 (IO21), U4.8 (SDA), U5.15 (SDA)
SRC: C8.2, D3.2 (A), L2.1, Q2.3 (D)
SS_SD: D12.1, J2.P2 (CD/DAT3), R21.1, U2.4 (IO4)
TX: TP_TX.TP, U2.25 (TXD0/GPIO16)
USB_D+: D1.1 (I/O1_1), U2.14 (IO13)
USB_D-: D1.3 (I/O2_1), U2.13 (IO12)
VBAT: C10BAT.1, Q1.3 (D), TP_VBAT.TP, U1.3 (VBAT), U4.2 (CELL), U4.3 (VDD)
VBUS: C1USB.1, C2USB1.1, C9BAT.1, CHG_LED.A, D1.5 (VBUS), D2.2 (ANODE), Q1.1 (G), R1.2, R4PWRUSB1.2, TP_VBUS.TP, U1.4 (VIN)
VRTC: C26.1, R_CAPACITOR.1, SUPERCAP.1, U5.14 (VBAT)
VUSB: J1.A4, J1.A9, J1.B4, J1.B9, R1.1

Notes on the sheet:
USB C connector & ESD protection
LDO Voltage Regulator
SD Card
ESP32 C6
Li-Po Battery Charging Controller
E-Paper Drive Circuit
Display Type Selector
E-Paper Display Header
EPD Power
Environmental Sensor BME688
Voltage Supervisor + Reset & Boot / IO Button
Battery ChargeLevel
External NORFlash64MB
SPI ESD Protection Lines
Qwiic / Stemma QT
Test Pads
RTC Module DS3231SN
Project name: OpenBook Done by: Stamatin Teodor

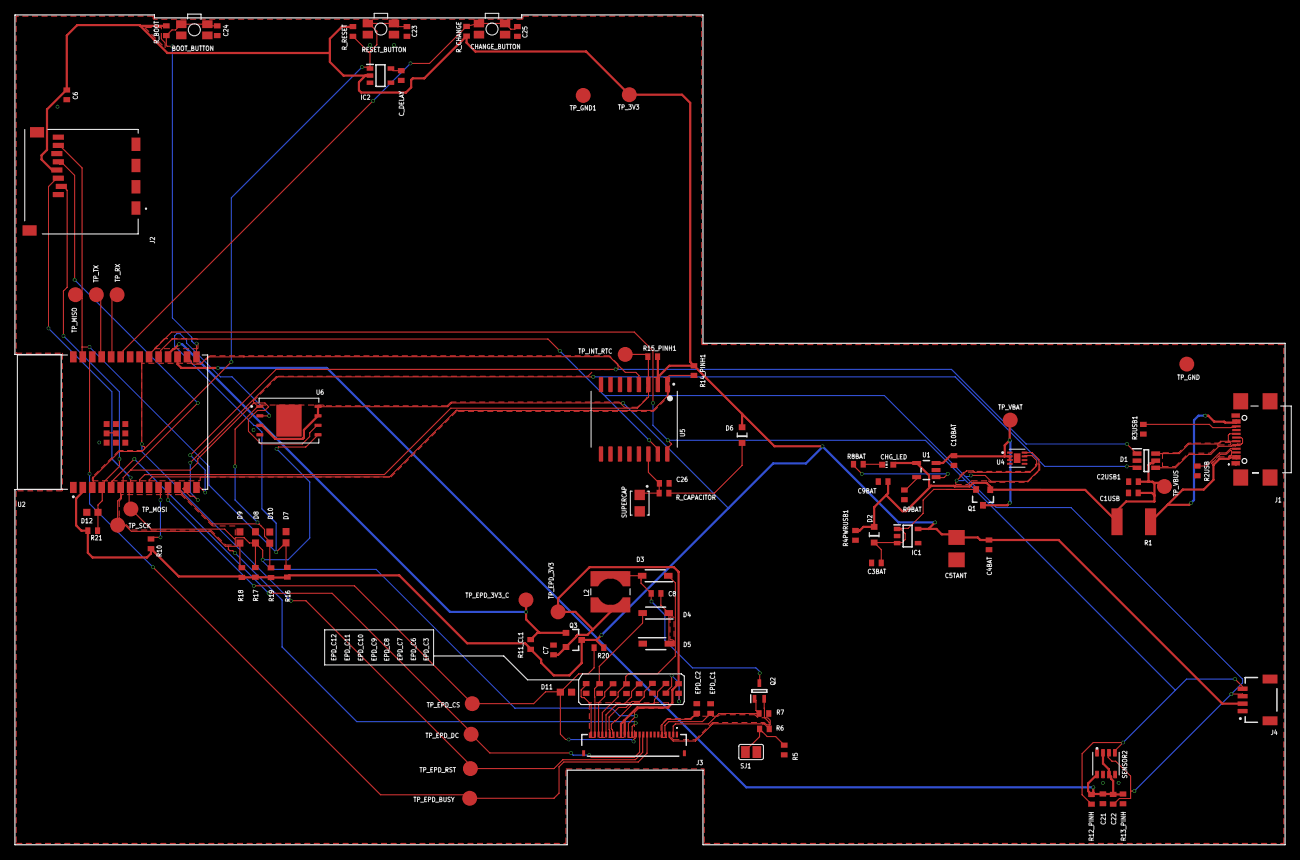
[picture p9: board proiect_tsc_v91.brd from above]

Board: 2 copper layers, 170.2 x 111.2 mm, 103 parts (0 on the bottom side), 55 nets.

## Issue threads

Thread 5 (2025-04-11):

PCB - Silkscreen

CarmenMaria17, 2025-04-11:
In the PCB design some components (like a part of the EPDs) do not have the name, you should add them.

TeodorStamatin, 2025-04-14:
done

Closed 2025-04-14.

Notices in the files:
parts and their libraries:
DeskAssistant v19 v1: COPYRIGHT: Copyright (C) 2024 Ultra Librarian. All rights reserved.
